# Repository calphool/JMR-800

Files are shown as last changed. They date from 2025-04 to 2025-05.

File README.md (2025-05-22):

# JMR-800

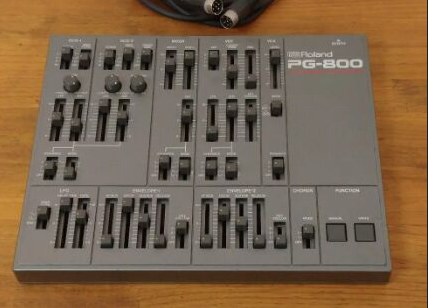
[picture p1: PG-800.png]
Picture of PG-800

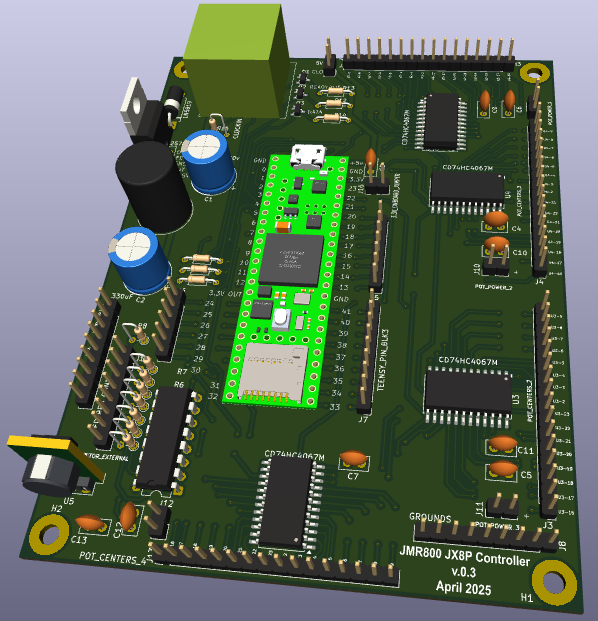
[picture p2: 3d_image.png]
PCB View of JMR-800


**JMR-800** is a modern, open-source clone of the Roland PG-800 hardware programmer, built around the Teensy 4.1 microcontroller. It provides real-time 
parameter control for vintage Roland synthesizers such as the JX-8P, MKS-70, and JX-10 using the original PG-800 communication protocol.

The JMR-800 replicates the original PG-800's functionality and physical interface, enabling direct, tactile editing of synthesizer parameters through a 
hands-on control surface.

## Features

- Compatible with Roland synths that support the PG-800 interface
- Built on Teensy 4.1 with fast, low-latency signal handling
- Accurate emulation of the PG-800 protocol (Clock, Ready, and Data lines)
- Designed for easy assembly and expansion
- Open hardware and firmware

## Status

This project is currently in active development. Basic communication and parameter changes are being validated. Contributions, forks, and collaboration are 
welcome.

April 10, 2025

- Redesigned PCB to get rid of the 74HC165 input bit shifter and replaced it with another analog mux/demux.  The total number of parameters that can be 
tweaked with the JX8P with the Vecoven PWM enhancement is 52.  So, I need to support at least 52 pots, and I can only support 48 with three muxes.  I mean
there are enough ADCs on the Teensy 4.1, that I probably could hack it and get those last 4 with separate ADC pins on the Teensy, but that's a pretty 
ineligant design, so I'll just add another mux/demux, get rid of the bit shifter, and limit my use of push buttons to just a few.  I technically only 
need one or two (the PG-800 only has 2), but I'll probably come up with a few odds and ends to implement (like maybe a way to load a whole sound from 
the JMR-800 by tweaking all of the parameters based on loading something from an SD card or something), so having a few more won't hurt.

- Decided to lay out the whole interface with my 3D printer as a template first.  This will allow me to cut cleaner holes into the aluminum case I think.
I'm using an aluminum case from Jameco that looks pretty retro / period correct.

April 14, 2025

Worked on the aluminum case a bit today.  Ran out of potentiometers, so ordered some more.

Picture of controller in process

April 17, 2025

Worked on the case some more.  Completed the potentiometer installation, got some knobs and installed them, though I don't like the fact that I didn't get 
an even number of red and blue, so I need to get another kit of them.  I also don't like the white ones, I think I'll remove those and replace with black.  
Finally, I couldn't find black 3mm screws, so I had to use stainless steel.  I'm going to change that, it ruins the asthetic.

Once I get all that settled, it's back to the software and firmware.  I redesigned the PCB about a week ago, but I think I'm going to need to do a slight 
additional redesign.  The four push buttons have two LEDs on them, a red one and a green one.  I really don't know exactly what I'm going to use them 
for yet, but I'm going to need an output shift register to manage all 8 of them (as well as current limiting resistors for each one, which would probably 
be best on the board rather than dangling and inline with the wires.

The software already works in a prototype way (two potentiometers that I tested with), so hopefully there won't be any surprises when I get all of them 
running.  I also added an additional 3.3V regulator that's optional on the new design, since I'm not altogether sure that the tiny little regulator on the 
Teensy can handle all the load I'm throwing at it.

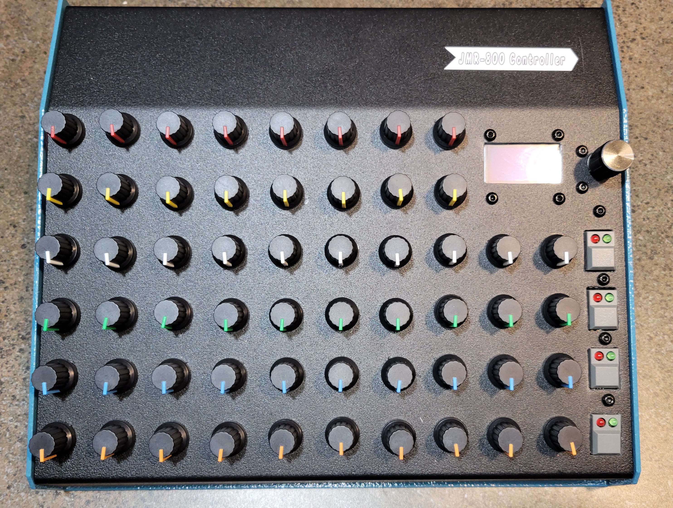
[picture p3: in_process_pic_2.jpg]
Picture of controller in process - top view


April 29, 2025

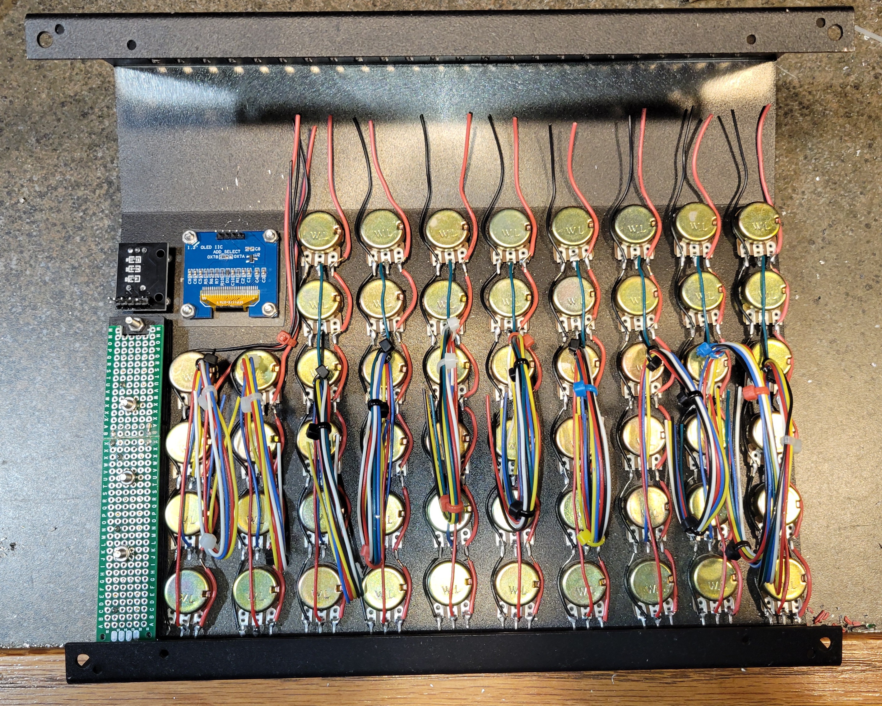
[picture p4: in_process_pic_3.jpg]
completed hardware


Got the new PCB and the rest of the hardware put together.  I wrote some temporary code that implements a "TEST MODE" that shows the condition of all 
the knobs.

May 3, 2025

I've updated the code quite a bit.  It now has 3 modes.  Run mode, Test mode, and Config mode.  I've been working on the Config mode.  You can change 
into these different modes by pressing Button 1 and Button 2 simultaneously.  When you configure a knob, you can change its name, its command byte, 
and select which type of knob it is.  I've got the command byte selection finished, and I'm working on the name update code now.  Once I get all the 
config stuff finished (perhaps this evening), I'll begin working on the Run mode.  This stuff was prototyped already with the earlier version of the 
board, so I'm pretty sure the code for interacting with the synth will work.

I may eventually implement some kind of "preset mode" that allows you to scroll through a given configuration of knobs, select it, and it would play 
all 56 knobs into the synthesizer.  This may be a submenu of the Run mode.  One step at a time of course...

May 5, 2025

***It's alive***!  I got the first fully functional code put together and just did about 15 minutes of testing.  It definitely works.  Though there's 
plenty to tweak.  Right now it's ignoring the parameter type and just sending values from 0 - 127, which does work, but it causes the screen to flicker 
on the synth for the parameters that only have a few set values.  I'm also wondering about how to manage noise from the potentiometers.  Although I 
used a smoothing algorithm, which does make them a lot less noisy, you still get odd little blips from time to time, and since they take whatever 
value the knob is at at the time, if you've just changed patches it can make a dramatic change to the sound.  I wonder if I should implement a 
kind of "lock / unlock" with one of the switches.  I could use green for "I'm unlocked and sending data to the synth" vs red for "I'm currently 
locked and not sending anything to the synth."

Lots and lots of small tweaks to work on now, but at least it's working.  The PWM mod that I installed from https://www.vecoven.com/superjx/styled/pwm.html
is pretty cool, especially with knobs that tweak its behavior in real time.

The other tweaks that the vecoven upgrade made to my firmware on my synth still takes some getting used to.  I'm going to have to read through the 
manuals for the vecoven upgrade really carefully, because it's pretty easy to get lost in the menus.  Maybe I could implement a "notepad" in the 
OLED screen of the JMR800 so it can remind me of stuff for the Vecoven upgrade.

One thing that I noticed that I'm going to have to deal with is the fact that not all the pots return the full range from 0 - 127 when sent through the 
ADC.  They came in a big bag from Aliexpress, so they're probably pretty low quality.  I'm going to need to implement some way to measure their min and 
max values, probably in the config mode, and then scale the pot value for each pot in software.

May 11, 2025

Finished all the screen stuff for Run mode, which is a pretty big milestone.  Also added an SVG file that represents the console layout. Working on an 
overlay using a Glowforge and acrylic.

May 14, 2025

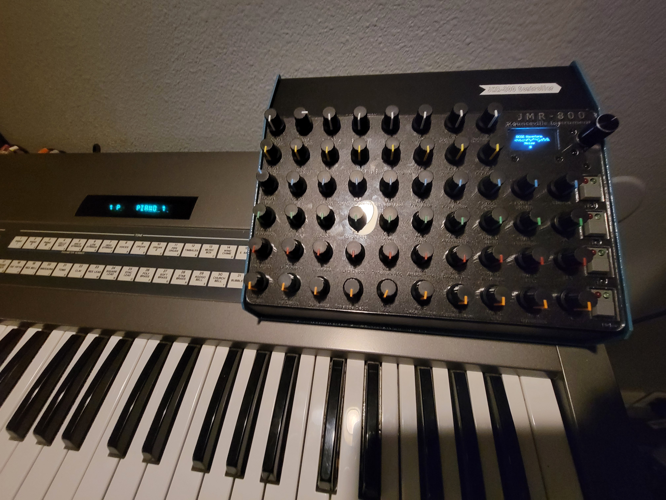
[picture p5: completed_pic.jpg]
completed device


May 22, 2025

I'm beginning to consider a major refactor of the software.  It all works pretty well, but there are some things I'd like to do that require a cleaner code 
base.  Basically I cobbled together the different system modes using a sloppy FSM rather than doing proper object oriented development whereby I set up 
modes as objects, and modes have screens, and screens have widgets, and widgets interact with controls, and so on.  By doing this, I'd have an infinitely 
more expandable user interface, and I really would like to implement a few interesting ideas.

First, I'd like to make it so that there are a collection of pre-sets that can be played into the JX8P on demand (like button 2 does right now with the 
default sound load, but with many many different presets).  The other thing I'd really like to do is implement something analogous to an arpeggiator, but 
rather than changing notes, it would change settings on a parameter.  For example, let's say you want to vary any arbitrary parameter (say something weird 
like chorus) with something like an LFO.  Let us further consider that you don't want to use one of the three or four LFO options available in the synth 
hardware itself, bur instead you want to be able to apply any arbitrary waveform to that chorus.  Although the "waveform" will be small (only 32 steps), it 
can take any form, and you simply draw the waveform in.  Then, when you go to a parameter for a given control, you depress the encoder button, and it pops 
up with a menu that lets you choose which stepper-LFO you want to use for this parameter.

All of this will require some significant refactoring.  I also want to introduce a microSD to the Teensy so that all this stuff can be stored and retrieved.  
Keep an eye out for a major update to the code base soon.

## License

This project is released under the MIT License.

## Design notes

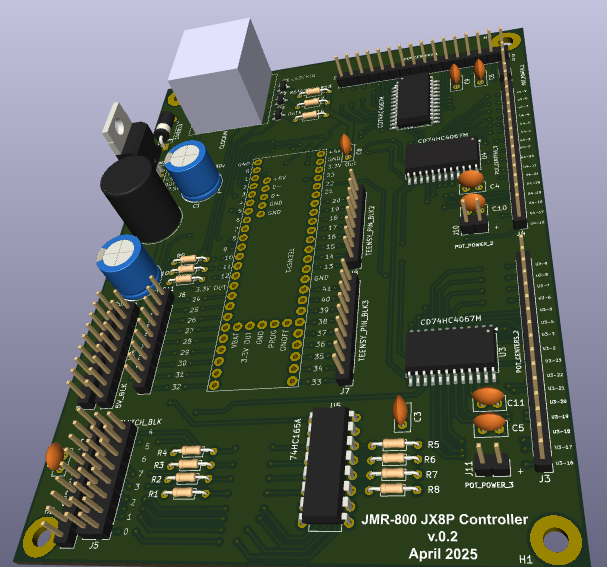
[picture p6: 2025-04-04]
3DView_PCB.png

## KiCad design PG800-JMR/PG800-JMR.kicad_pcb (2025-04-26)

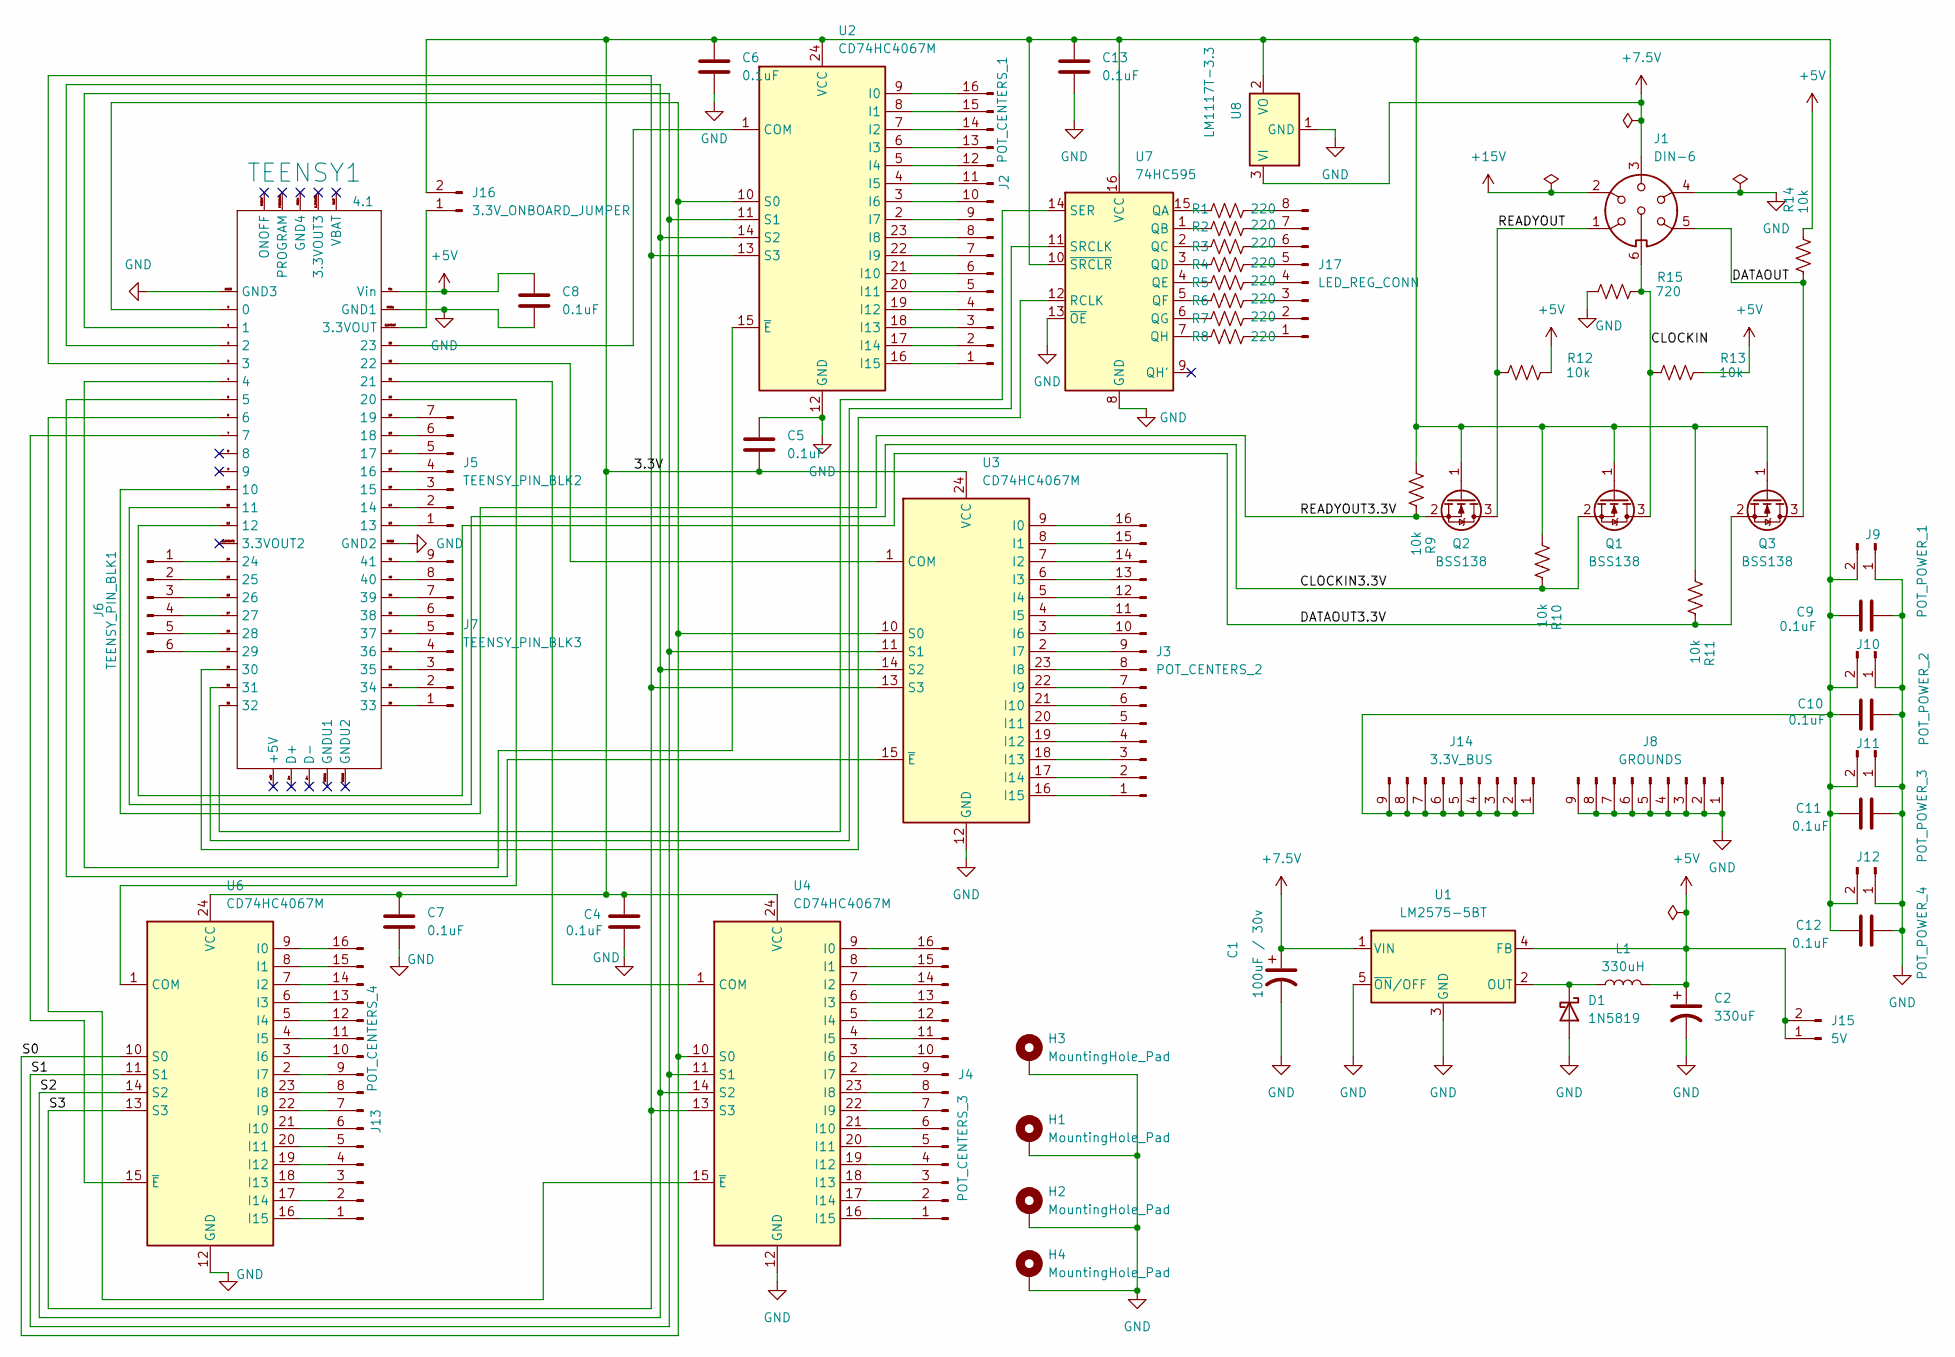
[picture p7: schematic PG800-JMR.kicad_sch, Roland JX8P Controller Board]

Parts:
C1: 100uF / 30v; CP_Radial_D10.0mm_P2.50mm
C2: 330uF; CP_Radial_D10.0mm_P5.00mm
C4, C5, C6, C7, C8, C9, C10, C11, C12, C13: 0.1uF; C_Disc_D5.0mm_W2.5mm_P2.50mm
D1: 1N5819; D_DO-15_P10.16mm_Horizontal
H1, H2, H3, H4: MountingHole_Pad; MountingHole_3.5mm_Pad
J1: DIN-6
J2: POT_CENTERS_1; PinHeader_1x16_P2.54mm_Vertical
J3: POT_CENTERS_2; PinHeader_1x16_P2.54mm_Vertical
J4: POT_CENTERS_3; PinHeader_1x16_P2.54mm_Vertical
J5: TEENSY_PIN_BLK2; PinHeader_1x07_P2.54mm_Vertical
J6: TEENSY_PIN_BLK1; PinHeader_1x06_P2.54mm_Vertical
J7: TEENSY_PIN_BLK3; PinHeader_1x09_P2.54mm_Vertical
J8: GROUNDS; PinHeader_1x09_P2.54mm_Vertical
J9: POT_POWER_1; PinHeader_1x02_P2.54mm_Vertical
J10: POT_POWER_2; PinHeader_1x02_P2.54mm_Vertical
J11: POT_POWER_3; PinHeader_1x02_P2.54mm_Vertical
J12: POT_POWER_4; PinHeader_1x02_P2.54mm_Vertical
J13: POT_CENTERS_4; PinHeader_1x16_P2.54mm_Vertical
J14: 3.3V_BUS; PinHeader_1x09_P2.54mm_Vertical
J15: 5V; PinHeader_1x02_P2.54mm_Vertical
J16: 3.3V_ONBOARD_JUMPER; PinHeader_1x02_P2.54mm_Vertical
J17: LED_REG_CONN; PinHeader_1x08_P2.54mm_Vertical
L1: 330uH; L_Radial_D12.0mm_P5.00mm_Fastron_11P
Q1, Q2, Q3: BSS138; SOT-23
R1, R2, R3, R4, R5, R6, R7, R8: 220; R_Axial_DIN0204_L3.6mm_D1.6mm_P2.54mm_Vertical
R9, R10, R11, R12, R13, R14: 10k; R_Axial_DIN0204_L3.6mm_D1.6mm_P7.62mm_Horizontal
R15: 720; R_Axial_DIN0204_L3.6mm_D1.6mm_P2.54mm_Vertical
TEENSY1: 4.1; Teensy4.1
U1: LM2575-5BT; TO-220-5_Vertical
U2, U3, U4, U6: CD74HC4067M; SOIC-24W_7.5x15.4mm_P1.27mm
U7: 74HC595; DIP-16_W7.62mm
U8: LM1117T-3.3; TO-220-3_Vertical

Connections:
+5V: C2.1, C8.1, J15.1, J15.2, L1.2, R12.1, R13.1, R14.1, TEENSY1.Vin, U1.4 (FB)
+7.5V: C1.1, J1.3, U1.1 (VIN), U8.3 (VI)
+15V: J1.2
/3.3V: C4.1, C5.2, C6.1, C7.1, C9.1, C10.1, C11.1, C12.1, C13.1, J9.2, J10.2, J11.2, J12.2, J14.1, J14.2, J14.3, J14.4, J14.5, J14.6, J14.7, J14.8, J14.9, J16.2, Q1.1 (G), Q2.1 (G), Q3.1 (G), R9.2, R10.2, R11.2, U2.24 (VCC), U3.24 (VCC), U4.24 (VCC), U6.24 (VCC), U7.10 (~SRCLR), U7.16 (VCC), U8.2 (VO)
/CLOCKIN: J1.6, Q1.3 (D), R13.2, R15.1
/CLOCKIN3.3V: Q1.2 (S), R10.1, TEENSY1.11
/DATAOUT: J1.5, Q3.3 (D), R14.2
/DATAOUT3.3V: Q3.2 (S), R11.1, TEENSY1.12
/READYOUT: J1.1, Q2.3 (D), R12.2
/READYOUT3.3V: Q2.2 (S), R9.1, TEENSY1.10
/S0: TEENSY1.0, U2.10 (S0), U3.10 (S0), U4.10 (S0), U6.10 (S0)
/S1: TEENSY1.1, U2.11 (S1), U3.11 (S1), U4.11 (S1), U6.11 (S1)
/S2: TEENSY1.2, U2.14 (S2), U3.14 (S2), U4.14 (S2), U6.14 (S2)
/S3: TEENSY1.3, U2.13 (S3), U3.13 (S3), U4.13 (S3), U6.13 (S3)
GND: C1.2, C2.2, C4.2, C5.1, C6.2, C7.2, C8.2, C9.2, C10.2, C11.2, C12.2, C13.2, D1.2 (A), H1.1, H2.1, H3.1, H4.1, J1.4, J8.1, J8.2, J8.3, J8.4, J8.5, J8.6, J8.7, J8.8, J8.9, J9.1, J10.1, J11.1, J12.1, R15.2, TEENSY1.GND1, TEENSY1.GND2, TEENSY1.GND3, U1.3 (GND), U1.5 (~ON/OFF), U2.12 (GND), U3.12 (GND), U4.12 (GND), U6.12 (GND), U7.8 (GND), U7.13 (~OE), U8.1 (GND)
unnamed: D1.1 (K), L1.1, U1.2 (OUT)
unnamed: J2.1, U2.16 (I15)
unnamed: J2.2, U2.17 (I14)
unnamed: J2.3, U2.18 (I13)
unnamed: J2.4, U2.19 (I12)
unnamed: J2.5, U2.20 (I11)
unnamed: J2.6, U2.21 (I10)
unnamed: J2.7, U2.22 (I9)
unnamed: J2.8, U2.23 (I8)
unnamed: J2.9, U2.2 (I7)
unnamed: J2.10, U2.3 (I6)
unnamed: J2.11, U2.4 (I5)
unnamed: J2.12, U2.5 (I4)
unnamed: J2.13, U2.6 (I3)
unnamed: J2.14, U2.7 (I2)
unnamed: J2.15, U2.8 (I1)
unnamed: J2.16, U2.9 (I0)
unnamed: J3.1, U3.16 (I15)
unnamed: J3.2, U3.17 (I14)
unnamed: J3.3, U3.18 (I13)
unnamed: J3.4, U3.19 (I12)
unnamed: J3.5, U3.20 (I11)
unnamed: J3.6, U3.21 (I10)
unnamed: J3.7, U3.22 (I9)
unnamed: J3.8, U3.23 (I8)
unnamed: J3.9, U3.2 (I7)
unnamed: J3.10, U3.3 (I6)
unnamed: J3.11, U3.4 (I5)
unnamed: J3.12, U3.5 (I4)
unnamed: J3.13, U3.6 (I3)
unnamed: J3.14, U3.7 (I2)
unnamed: J3.15, U3.8 (I1)
unnamed: J3.16, U3.9 (I0)
unnamed: J4.1, U4.16 (I15)
unnamed: J4.2, U4.17 (I14)
unnamed: J4.3, U4.18 (I13)
unnamed: J4.4, U4.19 (I12)
unnamed: J4.5, U4.20 (I11)
unnamed: J4.6, U4.21 (I10)
unnamed: J4.7, U4.22 (I9)
unnamed: J4.8, U4.23 (I8)
unnamed: J4.9, U4.2 (I7)
unnamed: J4.10, U4.3 (I6)
unnamed: J4.11, U4.4 (I5)
unnamed: J4.12, U4.5 (I4)
unnamed: J4.13, U4.6 (I3)
unnamed: J4.14, U4.7 (I2)
unnamed: J4.15, U4.8 (I1)
unnamed: J4.16, U4.9 (I0)
unnamed: J5.1, TEENSY1.13
unnamed: J5.2, TEENSY1.14
unnamed: J5.3, TEENSY1.15
unnamed: J5.4, TEENSY1.16
unnamed: J5.5, TEENSY1.17
unnamed: J5.6, TEENSY1.18
unnamed: J5.7, TEENSY1.19
unnamed: J6.1, TEENSY1.24
unnamed: J6.2, TEENSY1.25
unnamed: J6.3, TEENSY1.26
unnamed: J6.4, TEENSY1.27
unnamed: J6.5, TEENSY1.28
unnamed: J6.6, TEENSY1.29
unnamed: J7.1, TEENSY1.33
unnamed: J7.2, TEENSY1.34
unnamed: J7.3, TEENSY1.35
unnamed: J7.4, TEENSY1.36
unnamed: J7.5, TEENSY1.37
unnamed: J7.6, TEENSY1.38
unnamed: J7.7, TEENSY1.39
unnamed: J7.8, TEENSY1.40
unnamed: J7.9, TEENSY1.41
unnamed: J13.1, U6.16 (I15)
unnamed: J13.2, U6.17 (I14)
unnamed: J13.3, U6.18 (I13)
unnamed: J13.4, U6.19 (I12)
unnamed: J13.5, U6.20 (I11)
unnamed: J13.6, U6.21 (I10)
unnamed: J13.7, U6.22 (I9)
unnamed: J13.8, U6.23 (I8)
unnamed: J13.9, U6.2 (I7)
unnamed: J13.10, U6.3 (I6)
unnamed: J13.11, U6.4 (I5)
unnamed: J13.12, U6.5 (I4)
unnamed: J13.13, U6.6 (I3)
unnamed: J13.14, U6.7 (I2)
unnamed: J13.15, U6.8 (I1)
unnamed: J13.16, U6.9 (I0)
unnamed: J16.1, TEENSY1.3.3VOUT
unnamed: J17.1, R8.2
unnamed: J17.2, R7.2
unnamed: J17.3, R6.2
unnamed: J17.4, R5.2
unnamed: J17.5, R4.2
unnamed: J17.6, R3.2
unnamed: J17.7, R2.2
unnamed: J17.8, R1.2
unnamed: TEENSY1.23, U2.1 (COM)
unnamed: TEENSY1.4, U2.15 (~E)
unnamed: TEENSY1.22, U3.1 (COM)
unnamed: TEENSY1.5, U3.15 (~E)
unnamed: TEENSY1.21, U4.1 (COM)
unnamed: TEENSY1.6, U4.15 (~E)
unnamed: TEENSY1.20, U6.1 (COM)
unnamed: TEENSY1.7, U6.15 (~E)
unnamed: R1.1, U7.15 (QA)
unnamed: R2.1, U7.1 (QB)
unnamed: R3.1, U7.2 (QC)
unnamed: R4.1, U7.3 (QD)
unnamed: R5.1, U7.4 (QE)
unnamed: R6.1, U7.5 (QF)
unnamed: R7.1, U7.6 (QG)
unnamed: R8.1, U7.7 (QH)
unnamed: TEENSY1.30, U7.12 (RCLK)
unnamed: TEENSY1.32, U7.14 (SER)
unnamed: TEENSY1.31, U7.11 (SRCLK)

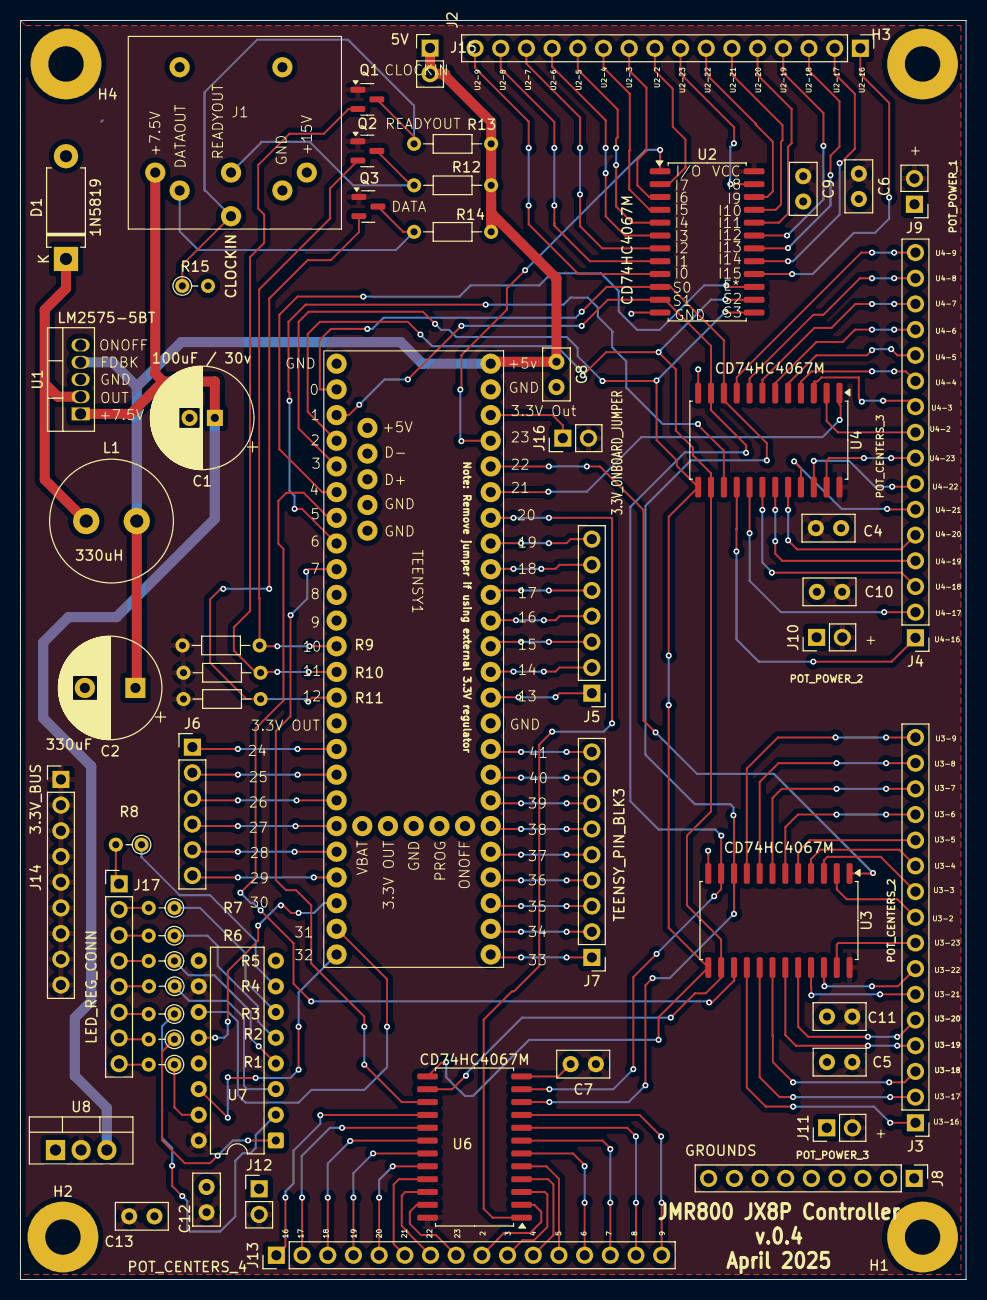
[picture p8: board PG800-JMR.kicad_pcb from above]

Board: 2 copper layers, 93.5 x 124.5 mm, 61 parts (0 on the bottom side), 129 nets.

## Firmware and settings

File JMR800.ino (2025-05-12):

#include "global.h"
#include <stdarg.h>
#include "JX8P.h"
#include <EEPROM.h>
#include "hardware.h"
#include "display.h"


// counter used to send all knob values to synth at the same time 
uint parmCtr;

uint8_t cmdValue = 0;
uint8_t byteValue = 0;



uint8_t systemMode;
uint8_t systemSubMode;

uint8_t activeKnob = 0;





// sends next command from given preset
void sendNextPresetParmToSynth(uint8_t presetNumber, uint8_t parmIX) {
  if(parmIX >= NUM_KNOBS)
    return;
  sendParameter(preset[parmIX].cmd, preset[parmIX].val);
}


/* --------------------------------------------------------------
   |  Logging routine                                           |
   -------------------------------------------------------------- */
void log(const String& s) {
  Serial.println(s);
  Serial.flush();
}


/* -------------------------------------------------------------------------
   |  getActiveKnob() - returns the active knob modded by the value passed |
   ------------------------------------------------------------------------- */
long getActiveKnob(long divisor) {
    long i = (lastEncoderPosition>>2) % divisor; 
    if(i < 0)
      i = 0;
    if(i > divisor)
      i = divisor-1;
    
    return i;
}


/* .------------------------------------------------------------.
   |  Initialization                                            |
   '------------------------------------------------------------' */
void setup() {
  Serial.begin(9600);
  EEPROM.begin();
  loadKnobs(); 

  typeCodes[TYPE_CODE_RANGE].cd = TYPE_CODE_RANGE;
  strcpy(typeCodes[TYPE_CODE_RANGE].typeCodeName, "Range");
  typeCodes[TYPE_CODE_WAVE_FORM].cd = TYPE_CODE_WAVE_FORM;
  strcpy(typeCodes[TYPE_CODE_WAVE_FORM].typeCodeName, "Wave Form");
  typeCodes[TYPE_CODE_3_2_1_OFF].cd = TYPE_CODE_3_2_1_OFF;
  strcpy(typeCodes[TYPE_CODE_3_2_1_OFF].typeCodeName, "3-2-1-Off");
  typeCodes[TYPE_CODE_0_TO_10].cd = TYPE_CODE_0_TO_10;
  strcpy(typeCodes[TYPE_CODE_0_TO_10].typeCodeName, "0 To 10");
  typeCodes[TYPE_CODE_OCTAVE].cd = TYPE_CODE_OCTAVE;
  strcpy(typeCodes[TYPE_CODE_OCTAVE].typeCodeName, "Octave");
  typeCodes[TYPE_CODE_MODE].cd = TYPE_CODE_MODE;
  strcpy(typeCodes[TYPE_CODE_MODE].typeCodeName, "Mode");
  typeCodes[TYPE_CODE_ENV2_GATE].cd = TYPE_CODE_ENV2_GATE;
  strcpy(typeCodes[TYPE_CODE_ENV2_GATE].typeCodeName, "Env2-Gate");
  typeCodes[TYPE_CODE_LFO_WAVE_FORM].cd = TYPE_CODE_LFO_WAVE_FORM;
  strcpy(typeCodes[TYPE_CODE_LFO_WAVE_FORM].typeCodeName, "LFO Wave Form");
  typeCodes[TYPE_CODE_2_1_OFF].cd = TYPE_CODE_2_1_OFF;
  strcpy(typeCodes[TYPE_CODE_2_1_OFF].typeCodeName, "2-1-Off");


  uint ctr=0;
        preset[ctr].cmd = 0x80; preset[ctr].val = 80; // DCO1 Range
  ctr++;preset[ctr].cmd = 0x81; preset[ctr].val = 112;// DCO1 Waveform
  ctr++;preset[ctr].cmd = 0x82; preset[ctr].val = 64; // DCO1 Tune
  ctr++;preset[ctr].cmd = 0x83; preset[ctr].val = 0;  // DCO1 LFO Depth
  ctr++;preset[ctr].cmd = 0x84; preset[ctr].val = 0;  // DCO1 Env Depth

  ctr++;preset[ctr].cmd = 0x85; preset[ctr].val = 80; // DCO2 Range
  ctr++;preset[ctr].cmd = 0x86; preset[ctr].val = 112;// DCO2 Waveform
  ctr++;preset[ctr].cmd = 0x87; preset[ctr].val = 0;  // DCO XMOD
  ctr++;preset[ctr].cmd = 0x88; preset[ctr].val = 64; // DCO2 Tune
  ctr++;preset[ctr].cmd = 0x89; preset[ctr].val = 58; // DCO2 Fine Tune
  ctr++;preset[ctr].cmd = 0x8A; preset[ctr].val = 0; // DCO2 LFO Depth
  ctr++;preset[ctr].cmd = 0x8B; preset[ctr].val = 0; // DCO2 Env Depth

  ctr++;preset[ctr].cmd = 0x8F; preset[ctr].val = 0; // DCO Dynamics
  ctr++;preset[ctr].cmd = 0x90; preset[ctr].val = 0; // DCO EG Mode

  ctr++;preset[ctr].cmd = 0x91; preset[ctr].val = 127; // Mix DCO1
  ctr++;preset[ctr].cmd = 0x92; preset[ctr].val = 127; // Mix DCO2
  ctr++;preset[ctr].cmd = 0x93; preset[ctr].val = 127; // Mix Env
  ctr++;preset[ctr].cmd = 0x94; preset[ctr].val = 0; // Mix Dynamics
  ctr++;preset[ctr].cmd = 0x95; preset[ctr].val = 0; // Mix EG Mode

  ctr++;preset[ctr].cmd = 0x96; preset[ctr].val = 0; // VCF HPF
  ctr++;preset[ctr].cmd = 0x97; preset[ctr].val = 55;// VCF Freq
  ctr++;preset[ctr].cmd = 0x98; preset[ctr].val = 0; // VCF Resonance
  ctr++;preset[ctr].cmd = 0x99; preset[ctr].val = 0; // VCF LFO
  ctr++;preset[ctr].cmd = 0x9A; preset[ctr].val = 107; // VCF Env
  ctr++;preset[ctr].cmd = 0x9B; preset[ctr].val = 127; // VCF Key
  ctr++;preset[ctr].cmd = 0x9C; preset[ctr].val = 127; // VCF Dynamics
  ctr++;preset[ctr].cmd = 0x9D; preset[ctr].val = 127; // VCF EG Mode

  ctr++;preset[ctr].cmd = 0x9E; preset[ctr].val = 100; // VCA Level
  ctr++;preset[ctr].cmd = 0x9F; preset[ctr].val = 0; // VCA Dynamics
  ctr++;preset[ctr].cmd = 0xAF; preset[ctr].val = 0; // VCA EG Mode

  ctr++;preset[ctr].cmd = 0xA1; preset[ctr].val = 64; // LFO Waveform
  ctr++;preset[ctr].cmd = 0xA2; preset[ctr].val = 0; // LFO Delay
  ctr++;preset[ctr].cmd = 0xA3; preset[ctr].val = 103; // LFO Rate
  ctr++;preset[ctr].cmd = 0xC6; preset[ctr].val = 0; // LFO Sync

  ctr++;preset[ctr].cmd = 0xA4; preset[ctr].val = 84; // EG Env1 Attk
  ctr++;preset[ctr].cmd = 0xA5; preset[ctr].val = 79; // EG Env1 Decay
  ctr++;preset[ctr].cmd = 0xA6; preset[ctr].val = 78; // EG Env1 Sust
  ctr++;preset[ctr].cmd = 0xA7; preset[ctr].val = 100; // EG Env1 Rel
  ctr++;preset[ctr].cmd = 0xA8; preset[ctr].val = 0; // EG Env1 Key

  ctr++;preset[ctr].cmd = 0xA9; preset[ctr].val = 0; // EG Env2 Attk
  ctr++;preset[ctr].cmd = 0xAA; preset[ctr].val = 15; // EG Env2 Decay
  ctr++;preset[ctr].cmd = 0xAB; preset[ctr].val = 75; // EG Env2 Sust
  ctr++;preset[ctr].cmd = 0xAC; preset[ctr].val = 0; // EG Env2 Rel
  ctr++;preset[ctr].cmd = 0xAD; preset[ctr].val = 0; // EG Env2 Key

  ctr++;preset[ctr].cmd = 0xB0; preset[ctr].val = 0; // PMW1 Width
  ctr++;preset[ctr].cmd = 0xB1; preset[ctr].val = 0; // PWM1 Env
  ctr++;preset[ctr].cmd = 0xB2; preset[ctr].val = 0; // PMW1 LFO
  ctr++;preset[ctr].cmd = 0xB3; preset[ctr].val = 0; // PWM2 Width
  ctr++;preset[ctr].cmd = 0xB4; preset[ctr].val = 0; // PWM2 Env
  ctr++;preset[ctr].cmd = 0xB5; preset[ctr].val = 0; // PWM2 LFO
  ctr++;preset[ctr].cmd = 0xC4; preset[ctr].val = 0; // PWM Dyna
  ctr++;preset[ctr].cmd = 0xCC; preset[ctr].val = 0; // PWM Mode
  ctr++;preset[ctr].cmd = 0xA0; preset[ctr].val = 0; // Chorus
  ctr++;preset[ctr].cmd = 0x00; preset[ctr].val = 0; // Unassigned
  ctr++;preset[ctr].cmd = 0x00; preset[ctr].val = 0; // Unassigned
  ctr++;preset[ctr].cmd = 0x00; preset[ctr].val = 0; // Unassigned

  systemMode = MODE_RUNNING;
  systemSubMode = SUBMODE_1;

  pinMode(PUSH_BTN_SW4_PIN, INPUT_PULLUP);
  pinMode(PUSH_BTN_SW3_PIN, INPUT_PULLUP);
  pinMode(PUSH_BTN_SW2_PIN, INPUT_PULLUP);
  pinMode(PUSH_BTN_SW1_PIN, INPUT_PULLUP);

  pinMode(ENCODER_SW_PIN,   INPUT_PULLUP);
  pinMode(ENCODER_CLK_PIN,  INPUT);
  pinMode(ENCODER_DT_PIN,   INPUT);

  pinMode(SHIFT_REG_SER,    OUTPUT);
  pinMode(SHIFT_REG_SRCLK,  OUTPUT);
  pinMode(SHIFT_REG_RCLK,   OUTPUT);

  for(uint i = 0; i < NUM_MUXES; i++) {
    pinMode(enablePins[i], OUTPUT);             // set enable pins as output
    digitalWrite(enablePins[i], HIGH);          // disable enable pins
  }
  for(uint i = 0; i < 4; i++) {
    pinMode(MuxAddressPins[i], OUTPUT);         // set mux pins as output
    digitalWrite(MuxAddressPins[i], LOW);       // set them all low
  }

  pinMode(READYOUT_PIN, OUTPUT);
  digitalWrite(READYOUT_PIN, LOW);

  pinMode(CLOCK_IN_PIN, INPUT_PULLUP);

  pinMode(DATA_OUT_PIN, OUTPUT);
  digitalWrite(READYOUT_PIN, LOW);
  
  display.begin(OLED_I2C_ADDRESS, false);
  display.clearDisplay();
  display.setTextSize(1);
  display.setTextColor(SH110X_WHITE);
  display.setTextWrap(false);
  display.display();

  log("Setting up ADC...");

  adc.adc0->setAveraging(4);
  adc.adc0->setConversionSpeed(ADC_CONVERSION_SPEED::MED_SPEED);
  adc.adc0->setSamplingSpeed(ADC_SAMPLING_SPEED::MED_SPEED); 

  log("Attaching interrupts...");

  attachInterrupt(digitalPinToInterrupt(CLOCK_IN_PIN), onPG800ClockFall, FALLING);

  log("Setting up DAC tables...");

  for(uint8_t i=0; i< NUM_MUXES; i++) {
      for(uint8_t j=0;j<16;j++) {
          AnalogValues[j][i] = 0;
          oldAnalogValues[j][i] = 0;
      }
  }

  // code to initialize the EEProm configuration if it hasn't already been set -- don't run this unless you're on a new Teensy, and only do it once
  /*
  ctr = 0;
  strcpy(knobConfigurations[ctr].name, "DCO1 Range");     knobConfigurations[ctr].cmdbyte = 0x80; knobConfigurations[ctr].typecode = TYPE_CODE_RANGE;         ctr++;
  strcpy(knobConfigurations[ctr].name, "DCO1 Waveform");  knobConfigurations[ctr].cmdbyte = 0x81; knobConfigurations[ctr].typecode = TYPE_CODE_WAVE_FORM;     ctr++;
  strcpy(knobConfigurations[ctr].name, "DCO1 Tune");      knobConfigurations[ctr].cmdbyte = 0x82; knobConfigurations[ctr].typecode = TYPE_CODE_OCTAVE;        ctr++;
  strcpy(knobConfigurations[ctr].name, "DCO1 LFO Depth"); knobConfigurations[ctr].cmdbyte = 0x83; knobConfigurations[ctr].typecode = TYPE_CODE_0_TO_10;       ctr++;
  strcpy(knobConfigurations[ctr].name, "DCO1 Env Depth"); knobConfigurations[ctr].cmdbyte = 0x84; knobConfigurations[ctr].typecode = TYPE_CODE_0_TO_10;       ctr++;

  strcpy(knobConfigurations[ctr].name, "DCO2 Range");     knobConfigurations[ctr].cmdbyte = 0x85; knobConfigurations[ctr].typecode = TYPE_CODE_RANGE;         ctr++;
  strcpy(knobConfigurations[ctr].name, "DCO2 Waveform");  knobConfigurations[ctr].cmdbyte = 0x86; knobConfigurations[ctr].typecode = TYPE_CODE_WAVE_FORM;     ctr++;
  strcpy(knobConfigurations[ctr].name, "DCO Crossmod");   knobConfigurations[ctr].cmdbyte = 0x87; knobConfigurations[ctr].typecode = TYPE_CODE_3_2_1_OFF;     ctr++;
  strcpy(knobConfigurations[ctr].name, "DCO2 Tune");      knobConfigurations[ctr].cmdbyte = 0x88; knobConfigurations[ctr].typecode = TYPE_CODE_OCTAVE;        ctr++;
  strcpy(knobConfigurations[ctr].name, "DCO2 Fine Tune"); knobConfigurations[ctr].cmdbyte = 0x89; knobConfigurations[ctr].typecode = TYPE_CODE_0_TO_10;       ctr++;
  strcpy(knobConfigurations[ctr].name, "DCO2 LFO Depth"); knobConfigurations[ctr].cmdbyte = 0x8A; knobConfigurations[ctr].typecode = TYPE_CODE_0_TO_10;       ctr++;
  strcpy(knobConfigurations[ctr].name, "DCO2 Env Depth"); knobConfigurations[ctr].cmdbyte = 0x8B; knobConfigurations[ctr].typecode = TYPE_CODE_0_TO_10;       ctr++;

  strcpy(knobConfigurations[ctr].name, "DCO Dynamics");   knobConfigurations[ctr].cmdbyte = 0x8F; knobConfigurations[ctr].typecode = TYPE_CODE_3_2_1_OFF;     ctr++;
  strcpy(knobConfigurations[ctr].name, "DCO EG Mode");    knobConfigurations[ctr].cmdbyte = 0x90; knobConfigurations[ctr].typecode = TYPE_CODE_MODE;          ctr++;

  strcpy(knobConfigurations[ctr].name, "Mix DCO1");       knobConfigurations[ctr].cmdbyte = 0x91; knobConfigurations[ctr].typecode = TYPE_CODE_0_TO_10;       ctr++;
  strcpy(knobConfigurations[ctr].name, "Mix DCO2");       knobConfigurations[ctr].cmdbyte = 0x92; knobConfigurations[ctr].typecode = TYPE_CODE_0_TO_10;       ctr++;
  strcpy(knobConfigurations[ctr].name, "Mix Env");        knobConfigurations[ctr].cmdbyte = 0x93; knobConfigurations[ctr].typecode = TYPE_CODE_0_TO_10;       ctr++;
  strcpy(knobConfigurations[ctr].name, "Mix EG Dynamic"); knobConfigurations[ctr].cmdbyte = 0x94; knobConfigurations[ctr].typecode = TYPE_CODE_3_2_1_OFF;     ctr++;
  strcpy(knobConfigurations[ctr].name, "Mix EG Mode");    knobConfigurations[ctr].cmdbyte = 0x95; knobConfigurations[ctr].typecode = TYPE_CODE_MODE;          ctr++;

  strcpy(knobConfigurations[ctr].name, "VCF HP Filter");  knobConfigurations[ctr].cmdbyte = 0x96; knobConfigurations[ctr].typecode = TYPE_CODE_3_2_1_OFF;     ctr++;
  strcpy(knobConfigurations[ctr].name, "VCF Cutoff Frq"); knobConfigurations[ctr].cmdbyte = 0x97; knobConfigurations[ctr].typecode = TYPE_CODE_0_TO_10;       ctr++;
  strcpy(knobConfigurations[ctr].name, "VCF Resonance");  knobConfigurations[ctr].cmdbyte = 0x98; knobConfigurations[ctr].typecode = TYPE_CODE_0_TO_10;       ctr++;
  strcpy(knobConfigurations[ctr].name, "VCF LFO");        knobConfigurations[ctr].cmdbyte = 0x99; knobConfigurations[ctr].typecode = TYPE_CODE_0_TO_10;       ctr++;
  strcpy(knobConfigurations[ctr].name, "VCF Env");        knobConfigurations[ctr].cmdbyte = 0x9A; knobConfigurations[ctr].typecode = TYPE_CODE_0_TO_10;       ctr++;
  strcpy(knobConfigurations[ctr].name, "VCF Key Follow"); knobConfigurations[ctr].cmdbyte = 0x9B; knobConfigurations[ctr].typecode = TYPE_CODE_0_TO_10;       ctr++;
  strcpy(knobConfigurations[ctr].name, "VCF EG Dynamic"); knobConfigurations[ctr].cmdbyte = 0x9C; knobConfigurations[ctr].typecode = TYPE_CODE_3_2_1_OFF;     ctr++;
  strcpy(knobConfigurations[ctr].name, "VCF EG Mode");    knobConfigurations[ctr].cmdbyte = 0x9D; knobConfigurations[ctr].typecode = TYPE_CODE_MODE;          ctr++;

  strcpy(knobConfigurations[ctr].name, "VCA Level");      knobConfigurations[ctr].cmdbyte = 0x9E; knobConfigurations[ctr].typecode = TYPE_CODE_0_TO_10;       ctr++;
  strcpy(knobConfigurations[ctr].name, "VCA EG Dynamic"); knobConfigurations[ctr].cmdbyte = 0x9F; knobConfigurations[ctr].typecode = TYPE_CODE_3_2_1_OFF;     ctr++;
  strcpy(knobConfigurations[ctr].name, "VCA EG Mode");    knobConfigurations[ctr].cmdbyte = 0xAF; knobConfigurations[ctr].typecode = TYPE_CODE_ENV2_GATE;     ctr++;

  strcpy(knobConfigurations[ctr].name, "LFO Waveform");   knobConfigurations[ctr].cmdbyte = 0xA1; knobConfigurations[ctr].typecode = TYPE_CODE_LFO_WAVE_FORM; ctr++;
  strcpy(knobConfigurations[ctr].name, "LFO Delay");      knobConfigurations[ctr].cmdbyte = 0xA2; knobConfigurations[ctr].typecode = TYPE_CODE_0_TO_10;       ctr++;
  strcpy(knobConfigurations[ctr].name, "LFO Rate");       knobConfigurations[ctr].cmdbyte = 0xA3; knobConfigurations[ctr].typecode = TYPE_CODE_0_TO_10;       ctr++;
  strcpy(knobConfigurations[ctr].name, "LFO Sync");       knobConfigurations[ctr].cmdbyte = 0xD0; knobConfigurations[ctr].typecode = TYPE_CODE_2_1_OFF;       ctr++;
  
  strcpy(knobConfigurations[ctr].name, "EG Env1 Attk");   knobConfigurations[ctr].cmdbyte = 0xA4; knobConfigurations[ctr].typecode = TYPE_CODE_0_TO_10;       ctr++;
  strcpy(knobConfigurations[ctr].name, "EG Env1 Decay");  knobConfigurations[ctr].cmdbyte = 0xA5; knobConfigurations[ctr].typecode = TYPE_CODE_0_TO_10;       ctr++;
  strcpy(knobConfigurations[ctr].name, "EG Env1 Sust");   knobConfigurations[ctr].cmdbyte = 0xA6; knobConfigurations[ctr].typecode = TYPE_CODE_0_TO_10;       ctr++;
  strcpy(knobConfigurations[ctr].name, "EG Env1 Rel");    knobConfigurations[ctr].cmdbyte = 0xA7; knobConfigurations[ctr].typecode = TYPE_CODE_0_TO_10;       ctr++;
  strcpy(knobConfigurations[ctr].name, "EG Env1 Key");    knobConfigurations[ctr].cmdbyte = 0xA8; knobConfigurations[ctr].typecode = TYPE_CODE_3_2_1_OFF;     ctr++;
  strcpy(knobConfigurations[ctr].name, "EG Env2 Attk");   knobConfigurations[ctr].cmdbyte = 0xA9; knobConfigurations[ctr].typecode = TYPE_CODE_0_TO_10;       ctr++;
  strcpy(knobConfigurations[ctr].name, "EG Env2 Decay");  knobConfigurations[ctr].cmdbyte = 0xAA; knobConfigurations[ctr].typecode = TYPE_CODE_0_TO_10;       ctr++;
  strcpy(knobConfigurations[ctr].name, "EG Env2 Sust");   knobConfigurations[ctr].cmdbyte = 0xAB; knobConfigurations[ctr].typecode = TYPE_CODE_0_TO_10;       ctr++;
  strcpy(knobConfigurations[ctr].name, "EG Env2 Rel");    knobConfigurations[ctr].cmdbyte = 0xAC; knobConfigurations[ctr].typecode = TYPE_CODE_0_TO_10;       ctr++;
  strcpy(knobConfigurations[ctr].name, "EG Env2 Key");    knobConfigurations[ctr].cmdbyte = 0xAD; knobConfigurations[ctr].typecode = TYPE_CODE_3_2_1_OFF;     ctr++;
  
  strcpy(knobConfigurations[ctr].name, "PWM Mode");       knobConfigurations[ctr].cmdbyte = 0xD6; knobConfigurations[ctr].typecode = TYPE_CODE_0_TO_10;       ctr++;
  strcpy(knobConfigurations[ctr].name, "PMW1 Width");     knobConfigurations[ctr].cmdbyte = 0xB0; knobConfigurations[ctr].typecode = TYPE_CODE_0_TO_10;       ctr++;
  strcpy(knobConfigurations[ctr].name, "PWM1 Env");       knobConfigurations[ctr].cmdbyte = 0xB1; knobConfigurations[ctr].typecode = TYPE_CODE_0_TO_10;       ctr++;
  strcpy(knobConfigurations[ctr].name, "PMW1 LFO");       knobConfigurations[ctr].cmdbyte = 0xB2; knobConfigurations[ctr].typecode = TYPE_CODE_0_TO_10;       ctr++;
  strcpy(knobConfigurations[ctr].name, "PWM2 Width");     knobConfigurations[ctr].cmdbyte = 0xB3; knobConfigurations[ctr].typecode = TYPE_CODE_0_TO_10;       ctr++;
  strcpy(knobConfigurations[ctr].name, "PWM2 Env");       knobConfigurations[ctr].cmdbyte = 0xB4; knobConfigurations[ctr].typecode = TYPE_CODE_0_TO_10;       ctr++;
  strcpy(knobConfigurations[ctr].name, "PWM2 LFO");       knobConfigurations[ctr].cmdbyte = 0xB5; knobConfigurations[ctr].typecode = TYPE_CODE_0_TO_10;       ctr++;
  strcpy(knobConfigurations[ctr].name, "PWM Dyna");       knobConfigurations[ctr].cmdbyte = 0xCE; knobConfigurations[ctr].typecode = TYPE_CODE_3_2_1_OFF;     ctr++;
  
  strcpy(knobConfigurations[ctr].name, "Chorus");         knobConfigurations[ctr].cmdbyte = 0xA0; ctr++;

  strcpy(knobConfigurations[ctr].name, "Unassigned");     knobConfigurations[ctr].cmdbyte = 0x00; ctr++;
  strcpy(knobConfigurations[ctr].name, "Unassigned");     knobConfigurations[ctr].cmdbyte = 0x00; ctr++;
  strcpy(knobConfigurations[ctr].name, "Unassigned");     knobConfigurations[ctr].cmdbyte = 0x00; ctr++;
  saveKnobs();
  */

  log("Initialized.");
}



/* .----------------------------------------------------------------------------------------------------.
   |  sendParameterToSynth() code to figure out what to send based on knob type                         |
   '----------------------------------------------------------------------------------------------------' */
void sendParameterToSynth(uint i) {
    /* code to ignore noise and jitter */
    uint kv = knobValueAt(i);

    if(knobConfigurations[i].typecode == TYPE_CODE_0_TO_10 || knobConfigurations[i].typecode == TYPE_CODE_OCTAVE) {
      sendParameter(knobConfigurations[i].cmdbyte, 127-knobValueAt(i)); // reverse the values so the knob goes clockwise
      return;
    }

    if(knobConfigurations[i].typecode == TYPE_CODE_LFO_WAVE_FORM || knobConfigurations[i].typecode == TYPE_CODE_2_1_OFF) {
      if(kv < 32)
        sendParameter(knobConfigurations[i].cmdbyte, 16); // Random      , Off      
      else
      if(kv < 64)
        sendParameter(knobConfigurations[i].cmdbyte, 48); // Square Wave , 1
      else
        sendParameter(knobConfigurations[i].cmdbyte, 96); // Triangle    , 2      

      return;
    }

    if(knobConfigurations[i].typecode == TYPE_CODE_ENV2_GATE) {
      if(kv < 64)
        sendParameter(knobConfigurations[i].cmdbyte, 32); // Gate
      else
        sendParameter(knobConfigurations[i].cmdbyte, 96); // Normal

      return;
    }
  
    if(knobConfigurations[i].typecode == TYPE_CODE_RANGE || knobConfigurations[i].typecode == TYPE_CODE_WAVE_FORM || 
       knobConfigurations[i].typecode == TYPE_CODE_3_2_1_OFF || knobConfigurations[i].typecode == TYPE_CODE_MODE) {
        if(kv < 32) {
          sendParameter(knobConfigurations[i].cmdbyte, 16); // range 16', Noise, OFF, Env-2-Inverted
          return;
        }
        else
        if(kv < 64) {
          sendParameter(knobConfigurations[i].cmdbyte, 48); // range 8', Sawtooth, 1, Env-2-Normal
          return;
        }
        else
        if(kv < 96) {
          sendParameter(knobConfigurations[i].cmdbyte, 80); // range 4', Pulse, 2, Env-1-Inverted
          return;
        }

        sendParameter(knobConfigurations[i].cmdbyte, 112); // range 2', Square, 3, Env-1-Normal
        return;
    }

}
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
void loop() {
  handleControlStatus();
  handleDisplays();
}

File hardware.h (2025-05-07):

#include <Wire.h>
#include <ADC.h>
#include <Encoder.h>
#include <vector>



#ifndef HARDWARE_h
#define HARDWARE_h


extern void log(const String& s);

ADC adc;

// encoder position
long lastEncoderPosition = 0;



// LED pattern buffer
uint8_t ledPattern = 0b00000000;

// MUX enable pins
#define U2_ENABLE_PIN 4
#define U3_ENABLE_PIN 5
#define U4_ENABLE_PIN 6
#define U6_ENABLE_PIN 7

// ADC input pins
#define U2_ANALOG_IN_PIN 23
#define U3_ANALOG_IN_PIN 22
#define U4_ANALOG_IN_PIN 21
#define U6_ANALOG_IN_PIN 20

// MUX address pins
#define S0_PIN 0
#define S1_PIN 1
#define S2_PIN 2 
#define S3_PIN 3

#define NUM_MUXES 4

// synthesizer input pins
#define READYOUT_PIN 10
#define CLOCK_IN_PIN 11
#define DATA_OUT_PIN 12

// OLED screen I2C address
#define OLED_I2C_ADDRESS 0x3c

// Button pins
#define PUSH_BTN_SW4_PIN 29
#define PUSH_BTN_SW3_PIN 28
#define PUSH_BTN_SW2_PIN 27
#define PUSH_BTN_SW1_PIN 26

// array of button pins
#define NUM_BUTTONS 4
const uint8_t buttonPins[NUM_BUTTONS] = {
  PUSH_BTN_SW1_PIN,
  PUSH_BTN_SW2_PIN,
  PUSH_BTN_SW3_PIN,
  PUSH_BTN_SW4_PIN
};


// buffer for values from ADC, and shadow copy for detecting changes
uint16_t AnalogValues[16][NUM_MUXES];
uint16_t oldAnalogValues[16][NUM_MUXES];



// array of pins for mux enable
uint enablePins[NUM_MUXES] = { U2_ENABLE_PIN, U3_ENABLE_PIN, U4_ENABLE_PIN, U6_ENABLE_PIN };

// array of pins for MUX addresses
uint MuxAddressPins[4] = { S0_PIN, S1_PIN, S2_PIN, S3_PIN };

// array of analog ADC input pins
uint analogInPins[NUM_MUXES] = { U2_ANALOG_IN_PIN, U3_ANALOG_IN_PIN, U4_ANALOG_IN_PIN , U6_ANALOG_IN_PIN};


// timer value for monitoring frequency of potentiometer scans
static unsigned long lastPotScanTime = 0;

// button lights shift register pins
#define SHIFT_REG_SER 32
#define SHIFT_REG_SRCLK 31
#define SHIFT_REG_RCLK 30

// Encoder pins
#define ENCODER_CLK_PIN 13
#define ENCODER_DT_PIN 14
#define ENCODER_SW_PIN 15

Encoder encoderKnob(ENCODER_CLK_PIN, ENCODER_DT_PIN);

// vector for de-duplicating messages sent to synthesizer
struct SentCommand {
  uint8_t paramID;
  uint8_t value;
  unsigned long timestamp;
};

std::vector<SentCommand> recentCommands;
const unsigned long COMMAND_TIMEOUT = 250;  // milliseconds

// button statuses
static bool bEncoderBtn = false;
static bool bPrevEncoderBtn = false;

// used for bit banging PG800 serial protocol
volatile int bitIndex = -1;
volatile uint16_t sendBuffer = 0;

// button state variables
uint8_t buttonStates[NUM_BUTTONS] = {0}; // Current button state (0 or 1)
uint8_t prevButtonStates[NUM_BUTTONS] = {0}; // Previous button state


/* --------------------------------------------------------------
   |  Set the muxes address value                               |
   |      Invoked by: gatherPotentiometerValues()               |
   -------------------------------------------------------------- */
void setAddressPins(uint val) {
  if(val & 0x01) digitalWrite(S0_PIN, HIGH); else digitalWrite(S0_PIN, LOW);
  if(val & 0x02) digitalWrite(S1_PIN, HIGH); else digitalWrite(S1_PIN, LOW);
  if(val & 0x04) digitalWrite(S2_PIN, HIGH); else digitalWrite(S2_PIN, LOW);
  if(val & 0x08) digitalWrite(S3_PIN, HIGH); else digitalWrite(S3_PIN, LOW);
  delayMicroseconds(5);
}



/* --------------------------------------------------------------
   |  Gather potentiometer values every quarter second          |
   |  Invoked by: loop()                                        |
   -------------------------------------------------------------- */
static int iGatherCtr = 0;
void gatherPotentiometerValues() {
  if(millis() - lastPotScanTime < 50)
    return;

  iGatherCtr++;
  lastPotScanTime = millis();
  for(uint8_t muxCtr = 0; muxCtr < NUM_MUXES; muxCtr++) {
      digitalWrite(enablePins[muxCtr], LOW);  // enable this mux
      for(uint8_t addr = 0; addr < 16; addr++) {
        setAddressPins(addr);
        uint16_t raw = adc.adc0->analogRead(analogInPins[muxCtr]);
        raw = raw >> 2;          // (1024 / 4 = 256)
        raw = (AnalogValues[addr][muxCtr] * 7 + raw) >> 3;  // smoothed value (multiplies original value by 7 then adds new, then averages)
        AnalogValues[addr][muxCtr] = raw;
        if(iGatherCtr % 10 == 0) // store a copy of the current AnalogValues() periodically
            oldAnalogValues[addr][muxCtr] = AnalogValues[addr][muxCtr];
      }
      digitalWrite(enablePins[muxCtr], HIGH); // disable this mux
      delayMicroseconds(5);
  }
}
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

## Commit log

2025-04-03 added schematics and PCBs in KiCad format
    [PG800-JMR.kicad_pcb, PG800-JMR.kicad_sch]
2025-04-04 updated kicad drawings, tweaked code slightly
    [PG800-JMR.kicad_pcb, PG800-JMR.kicad_sch]
2025-04-05 update for PWM upgrade
2025-04-08 updated PCB design, added optional 3.3V regulator, added another mux
    [PG800-JMR.kicad_pcb, PG800-JMR.kicad_sch]
2025-04-18 updated 3d image
    [PG800-JMR.kicad_pcb, PG800-JMR.kicad_sch]
2025-04-26 Fixed LM1117-3.3, pins in wrong order
    [PG800-JMR.kicad_pcb, PG800-JMR.kicad_sch]
2025-05-07 updated code to enable Button 2 to send a basic sound to work from
2025-05-07 fixed commented out cmds in case we need to reload eeprom
    [JMR800.ino]
2025-05-07 broke up files into main, display, global, and hardware
    [JMR800.ino, display.h, hardware.h]
2025-05-12 made small tweak to button placement
